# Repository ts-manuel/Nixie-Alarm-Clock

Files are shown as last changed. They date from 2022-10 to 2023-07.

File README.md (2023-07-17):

# Nixie Alarm Clock
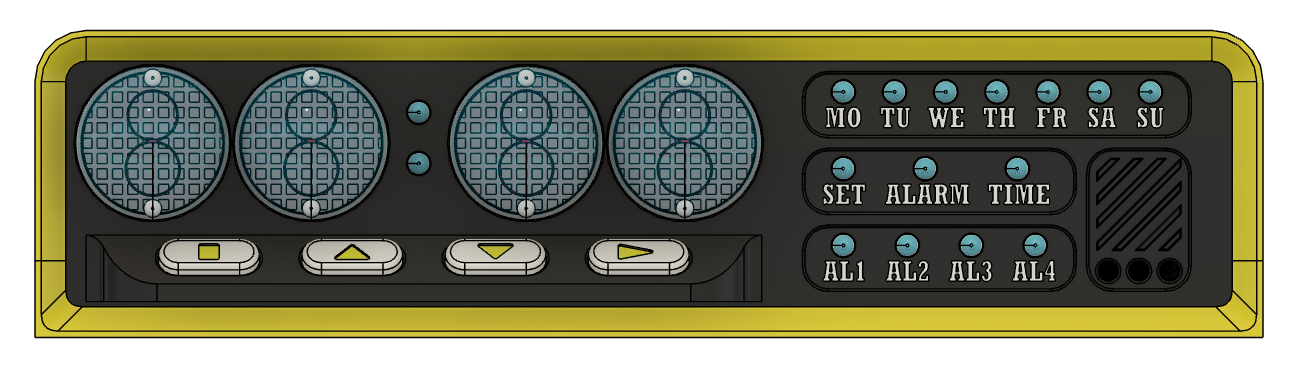
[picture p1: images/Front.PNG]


<!-- TABLE OF CONTENTS -->
<details open="open">
  <summary>Table of Contents</summary>
  <ol>
    <li><a href="#about-the-project">About The Project</a></li>
    <li><a href="#schematics">Schematics</a></li>
    <li><a href="#getting-started">Block Diagram</a></li>
  </ol>
</details>

<!-- ABOUT THE PROJECT -->
## About The Project

<!-- SCHEMATICS -->
## Schematics
[Nixie Alarm Clock - Base.pdf](Nixie%20Alarm%20Clock%20-%20Base.pdf)\
[Nixie Alarm Clock - Display.pdf](Nixie%20Alarm%20Clock%20-%20Display.pdf)

<!-- GETTING STARTED -->
## Getting Started

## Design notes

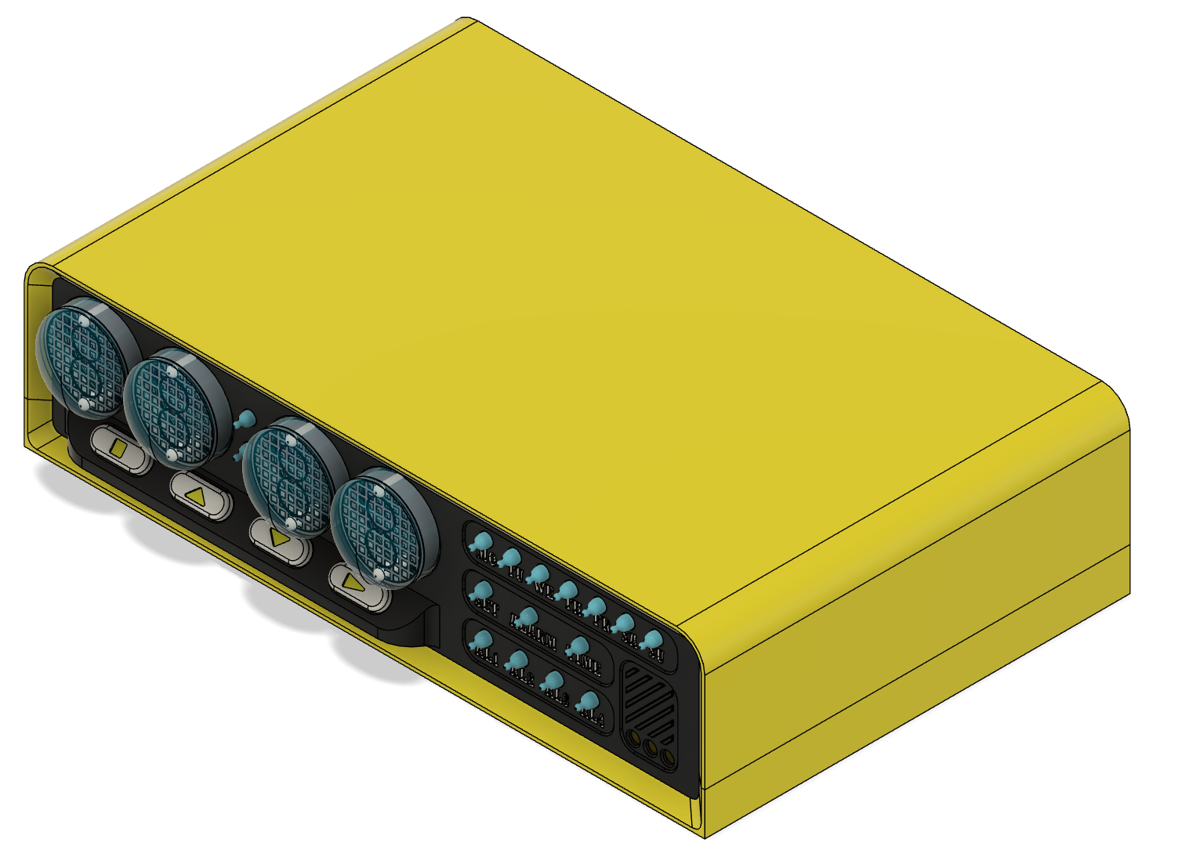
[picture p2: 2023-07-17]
images/home.PNG

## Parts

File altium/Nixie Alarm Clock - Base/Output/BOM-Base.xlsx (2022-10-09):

Mouser Part Number | Description | Designator | Value | Quantity | Footprint
710-150060VS75000 | Standard LEDs - SMD WL-SMCW SMDMono TpVw Waterclr 0603 BrtGrn | D6 | Green | 1 | LED-SMD-0603-1.6X0.8
80-ESK228M025AL4AA | ALU 25V 2200uF RippleCurrent=1.3A 20% | C1, C2 | 2200u | 2 | CAPPRD500W60D1300H2700
603-RC0603FR-07470RL | Thick Film - SMD 75V 1/10W 470 ohm 0603 1% | R9 | 470R | 1 | RES-0603
710-885012007083 | MLCC - SMD 100V 150pF NP0 0805 5% | C35, C36, C37, C38 | 150p | 4 | CAP-0805
603-RC0603FR-07100RL | Thick Film - SMD 75V 1/10W 100 ohm 0603 1% | R14, R15, R16, R23, R24, R25, R26, R29, R30, R31, R32, R34, R36, R37, R38, R39, R40, R41, R42, R43, R44, R45, R46, R47, R48, R52, R53, R55 | 100R | 28 | RES-0603
80-C0603C104M4RAC | MLCC - SMD 16V 100nF X7R 0603 20% | C3, C6, C12, C13, C15, C16, C24, C28, C29, C31, C32, C33, C34 | 100n | 13 | CAP-0603
603-RC0603FR-0754K9L | Thick Film - SMD 75V 1/10W 54.9K ohm 0603 1% | R11 | 54K9 | 1 | RES-0603
603-RC0603FR-0747KL | Thick Film - SMD 75V 1/10W 47K ohm 0603 1% | R17, R18, R19, R20, R21, R22, R27, R28, R33, R50, R54 | 47K | 11 | RES-0603
520-.327-6-34BT | Crystal 32.768kHz 20ppm 6pF -40C +85C | X2 | 32.768 KHz | 1 | XTAL-ECS-3.2 mm x 1.5 mm
80-C0603C270J5G | MLCC - SMD 50V 27pF NP0 0603 5% | C18, C19 | 27p | 2 | CAP-0603
187-CL21A106KAYNNNE | MLCC - SMD 25V 10uF X5R 10% | C4, C5, C7, C8, C9, C10, C11, C14, C17, C22, C23, C26, C27, C39 | 10u | 14 | CAP-0805
603-RC0603FR-0710KL | Thick Film - SMD 75V 1/10W 10K ohm 0603 1% | R13 | 10K | 1 | RES-0603
603-CC603JRNPO9BN8R2 | MLCC - SMD 50V 8.2pF NP0 0603 5% | C20, C21 | 8.2p | 2 | CAP-0603
449-LFXTAL017619BULK | Crystal 7.168MHz 20ppm 30pF -10C +60C | X1 | 7.168 MHz | 1 | XTAL1140X490X430_HC49
603-RC0603FR-074K7L | Thick Film - SMD 75V 1/10W 4.7K ohm 0603 1% | R1, R2, R3, R4, R6, R8, R49, R51 | 4K7 | 8 | RES-0603
963-NRS4018T3R3MDGJ | Fixed Inductor 4018 3.3uH 66mOhms +/-20%Tol 2300mA | L1 | 3u3 | 1 | INDP4040X18M
81-GRM185C1H152JA01J | MLCC - SMD 50V 1.5nF NP0 0603 5% | C25, C30 | 1n5 | 2 | CAP-0603
603-RC0603FR-071K6L | Thick Film - SMD 75V 1/10W 1.6K ohm 0603 1% | R12 | 1K6 | 1 | RES-0603
603-RC0603FR-071KL | Thick Film - SMD 75V 1/10W 1K ohm 0603 1% | R10, R35 | 1K | 2 | RES-0603
603-RC0805FR-071KL | Thick Film - SMD 150V 1/8W 1K ohm 0805 1% | R5, R7 | 1K | 2 | RES-0805
 |  | SW1 |  | 1 | Push Button 6mm TH
 | Header, 3-Pin | P4 |  | 1 | HDR1X3
 | Header, 5-Pin | P3 |  | 1 | HDR1X5
 | Screw Therminal Block 200 mil Pitch 2 Contacts | J3, J4, J5, J6 |  | 4 | SCREW-TH-BLOCK-200-2
 | Screw Therminal Block 200 mil Pitch 4 Contacts | J7 |  | 1 | SCREW-TH-BLOCK-200-4
517-SD-RSMT-2-MQ-WF | Connettori per schede di memoria SD CARD CONNECTOR | J2 |  | 1 | SD 3M SD-RSMT-2-MQ-WF
538-90130-1112 | Terminali e capicorda 2.54MM CGRIDIII HDR 12P V DR SHRD TIN | J1 |  | 1 | SHDR12W65P254_2X6_1758X975X1110P
579-24FJ64GA705IPT | Microcontrollori a 16 bit - MCU 16-bit, 16 MIPS, 64KB Flash, 16KB RAM | U8 |  | 1 | TSQFP50P900X900X120-48N
595-LMV358IDR | Low-Voltage Rail-to-Rail Output FET Input Dual Operational Amplifier | U10 |  | 1 | SOIC127P600X175-8N
595-PCM1754DBQR | Circuiti integrati convertitori D/A audio 24-Bit 192kHz Stereo Audio DAC | U9 |  | 1 | SOP64P600X175-16N
595-TPS561201DDCT | 4.5-V to 17-V Input, 1-A Synchronous Step-Down Voltage Regulator | U4 |  | 1 | SOT95P278X110-6N
621-1N4004 | Silicon Diode - 400V 50uA 1A | D1, D2, D3, D4 |  | 4 | DIODE-DO41
621-AZ1117IH-ADJTRG1 | LDO 15V Max 1.2V Dropout 1.35A Max | U5 |  | 1 | SOT230P700X180-4M
621-PAM8407DR | 2x3W Stereo Differential Input Class D Audio Amplifier with Up/Down Volume Control | U11 |  | 1 | SOIC127P600X175-16N
712-BAT-HLD-001 | Portabatterie a celle a bottone Linx CR2032 Battery Holder | B1 |  | 1 | BATHLD001-CR2032
782-H11A1 | Optocoupler, Phototransistor Output, With Base Connection | U1, U2, U3 |  | 3 | DIP762W51P254L889H508Q6N
863-BAS20LT3G | Silicon Diode - 200V 0.1uA 200mA | D5 |  | 1 | SOT95P240X110-3N
998-MIC2004-0.5YM5TR | Fixed 0.5A Current Limiting Power Distribution Switches | U7 |  | 1 | SOT23-5
998-MIC2548A-2YM | Programmable Current-Limit High-Side Switch | U6 |  | 1 | SOIC127P600X175-8N

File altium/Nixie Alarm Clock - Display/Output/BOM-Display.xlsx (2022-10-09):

Mouser Part Number | Description | Designator | Value | Quantity | Footprint
603-RT1206FRE07680KL | Thin Film Resistors 680K OHM 1% 50PPM 1/4W | R4, R9, R10, R15, R21, R31, R33, R34, R35, R36, R37, R38, R39, R40, R44, R45, R46, R47, R48, R49, R50, R51, R73, R94 | 680K | 24 | RES-1206
77-VJ0805A471JXBCBC | Condensatori in ceramica multistrato MLCC - SMD/SMT 0805 470pF 100volts C0G 5% | C9 | 470p | 1 | CAP-0805
667-ERJ-U6QFR30V | Resistori a pellicola spessa - SMD 0805 0.25W 1% .30ohms AEC-Q200 | R5, R6, R7, R8 | 300m | 4 | RES-0805
710-885342208002 | Condensatori in ceramica multistrato MLCC - SMD/SMT WCAP-CSMH 200V 0.1uF 1206 10% | C1, C2, C3, C4, C5, C8, C10, C11, C12, C13, C14, C15, C16, C17, C18, C19, C20 | 100nF | 17 | CAP-1206
704-DR127-820-R | Induttori fissi 82uH 4.0A 0.143ohms | L1 | 82uH | 1 | IND-DR127
652-TC33X-2-503E | Resistenze trimmer - SMD 3MM 50KOHMS 25% 0.1WATT OPEN FRM | R22, R32, R74 | 50K | 3 | TC33X2503E
603-RT0805FRE0747KL | Thin Film Resistors 1/8W 47K ohm 1% 50ppm | R14, R16, R23, R24, R25, R26, R41, R42, R43, R52, R53, R54, R55, R56, R57, R58, R59, R60, R61, R62, R63, R64, R65, R75, R76, R90, R91, R92, R93 | 47K | 29 | RES-0805
80-A768EB336M1GLAE45 | Condensatori a polimeri organici in alluminio 40V 33uF 20% ESR=45mOhms | C6, C7 | 33uF | 2 | CAPAE7366X60M
652-CR0805JW-150ELF | Resistori a pellicola spessa - SMD 15ohm 5% | R11 | 15R | 1 | RES-0805
603-RT0805FRE134K7L | Thin Film Resistors 4.7K ohm 1% 50 ppm | R1, R2, R3, R12, R13, R17, R18, R19, R20, R27, R28, R29, R30, R66, R67, R68, R69, R70, R71, R72, R77, R78, R79, R80, R81, R82, R83, R84, R85, R86, R87, R88, R89 | 4K7 | 33 | RES-0805
 |  | D5, D6, D7, D8 |  | 4 | IN4 NIXIE
 |  | SW1, SW2, SW3, SW4 |  | 4 | Push Button 6mm TH
78-BZM55C47 | Diodi Zener 47 Volt 0.5W 5% | D3, D4 |  | 2 | DIOMELF1913M
511-MC34063ABD-TR | DC-DC Converter 3.0 to 40V | U1 |  | 1 | SOIC-8_3.9X4.9
512-FDT86244 | MOSFET 150V N-Channel PowerTrench MOSFET | Q1 |  | 1 | SOT230P700X180-4M
538-90130-1112 | Terminali e capicorda 2.54MM CGRIDIII HDR 12P V DR SHRD TIN | J1 |  | 1 | SHDR12W65P254_2X6_1758X975X1110P
595-CD74HC595M96 | 8-Bit Shift Register | U2, U4, U6, U8, U10 |  | 5 | SOIC127P600X175-16N
595-SN75468DR | High Voltage Darlington Transistor Arrays | U3, U5, U7, U9, U11 |  | 5 | SOIC127P600X175-16N
621-MMBTA42-F | 300V NPN SMALL SIGNAL TRANSISTOR IN SOT23 | Q9, Q15, Q24, Q25, Q26, Q27, Q28, Q29, Q30, Q31, Q40 |  | 11 | SOT95P240X110-3N
621-MMBTA92-F | 300V PNP SMALL SIGNAL TRANSISTOR IN SOT23 | Q2, Q3, Q4, Q5, Q6, Q7, Q8, Q10, Q11, Q12, Q13, Q14, Q16, Q17, Q18, Q19, Q20, Q21, Q22, Q23, Q32, Q33, Q34, Q35, Q36, Q37, Q38, Q39, Q41, Q42, Q43, Q44, Q45, Q46, Q47, Q48, Q49 |  | 37 | SOT95P240X110-3N
696-GT-NE4H1125 | Lampade Std. Brightness Neon Lamp Tin Leads | N1, N2, N3, N4, N5, N6, N7, N8, N9, N10, N11, N12, N13, N14, N15, N16 |  | 16 | NE4 NEON LAMP
755-RFN2LAM4STR | Diodi - Uso generico, alimentazione, commutazione 400V 1.5A Io PMDTM | D1, D2 |  | 2 | SODFL472X100-2M

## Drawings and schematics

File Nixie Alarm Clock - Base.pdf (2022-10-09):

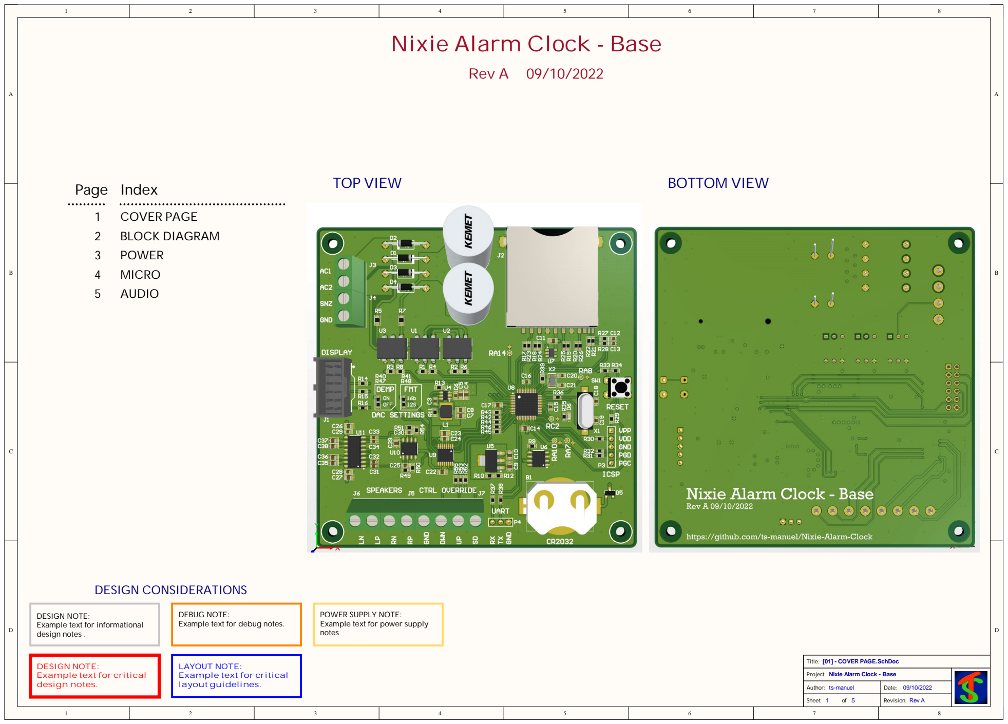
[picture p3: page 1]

DESIGN NOTE:
Example text for informational
design notes .

DEBUG NOTE:
Example text for debug notes.

POWER SUPPLY NOTE:
Example text for power supply
notes

Example text for critical
design notes.

LAYOUT NOTE:
layout guidelines.

Nixie Alarm Clock - Base

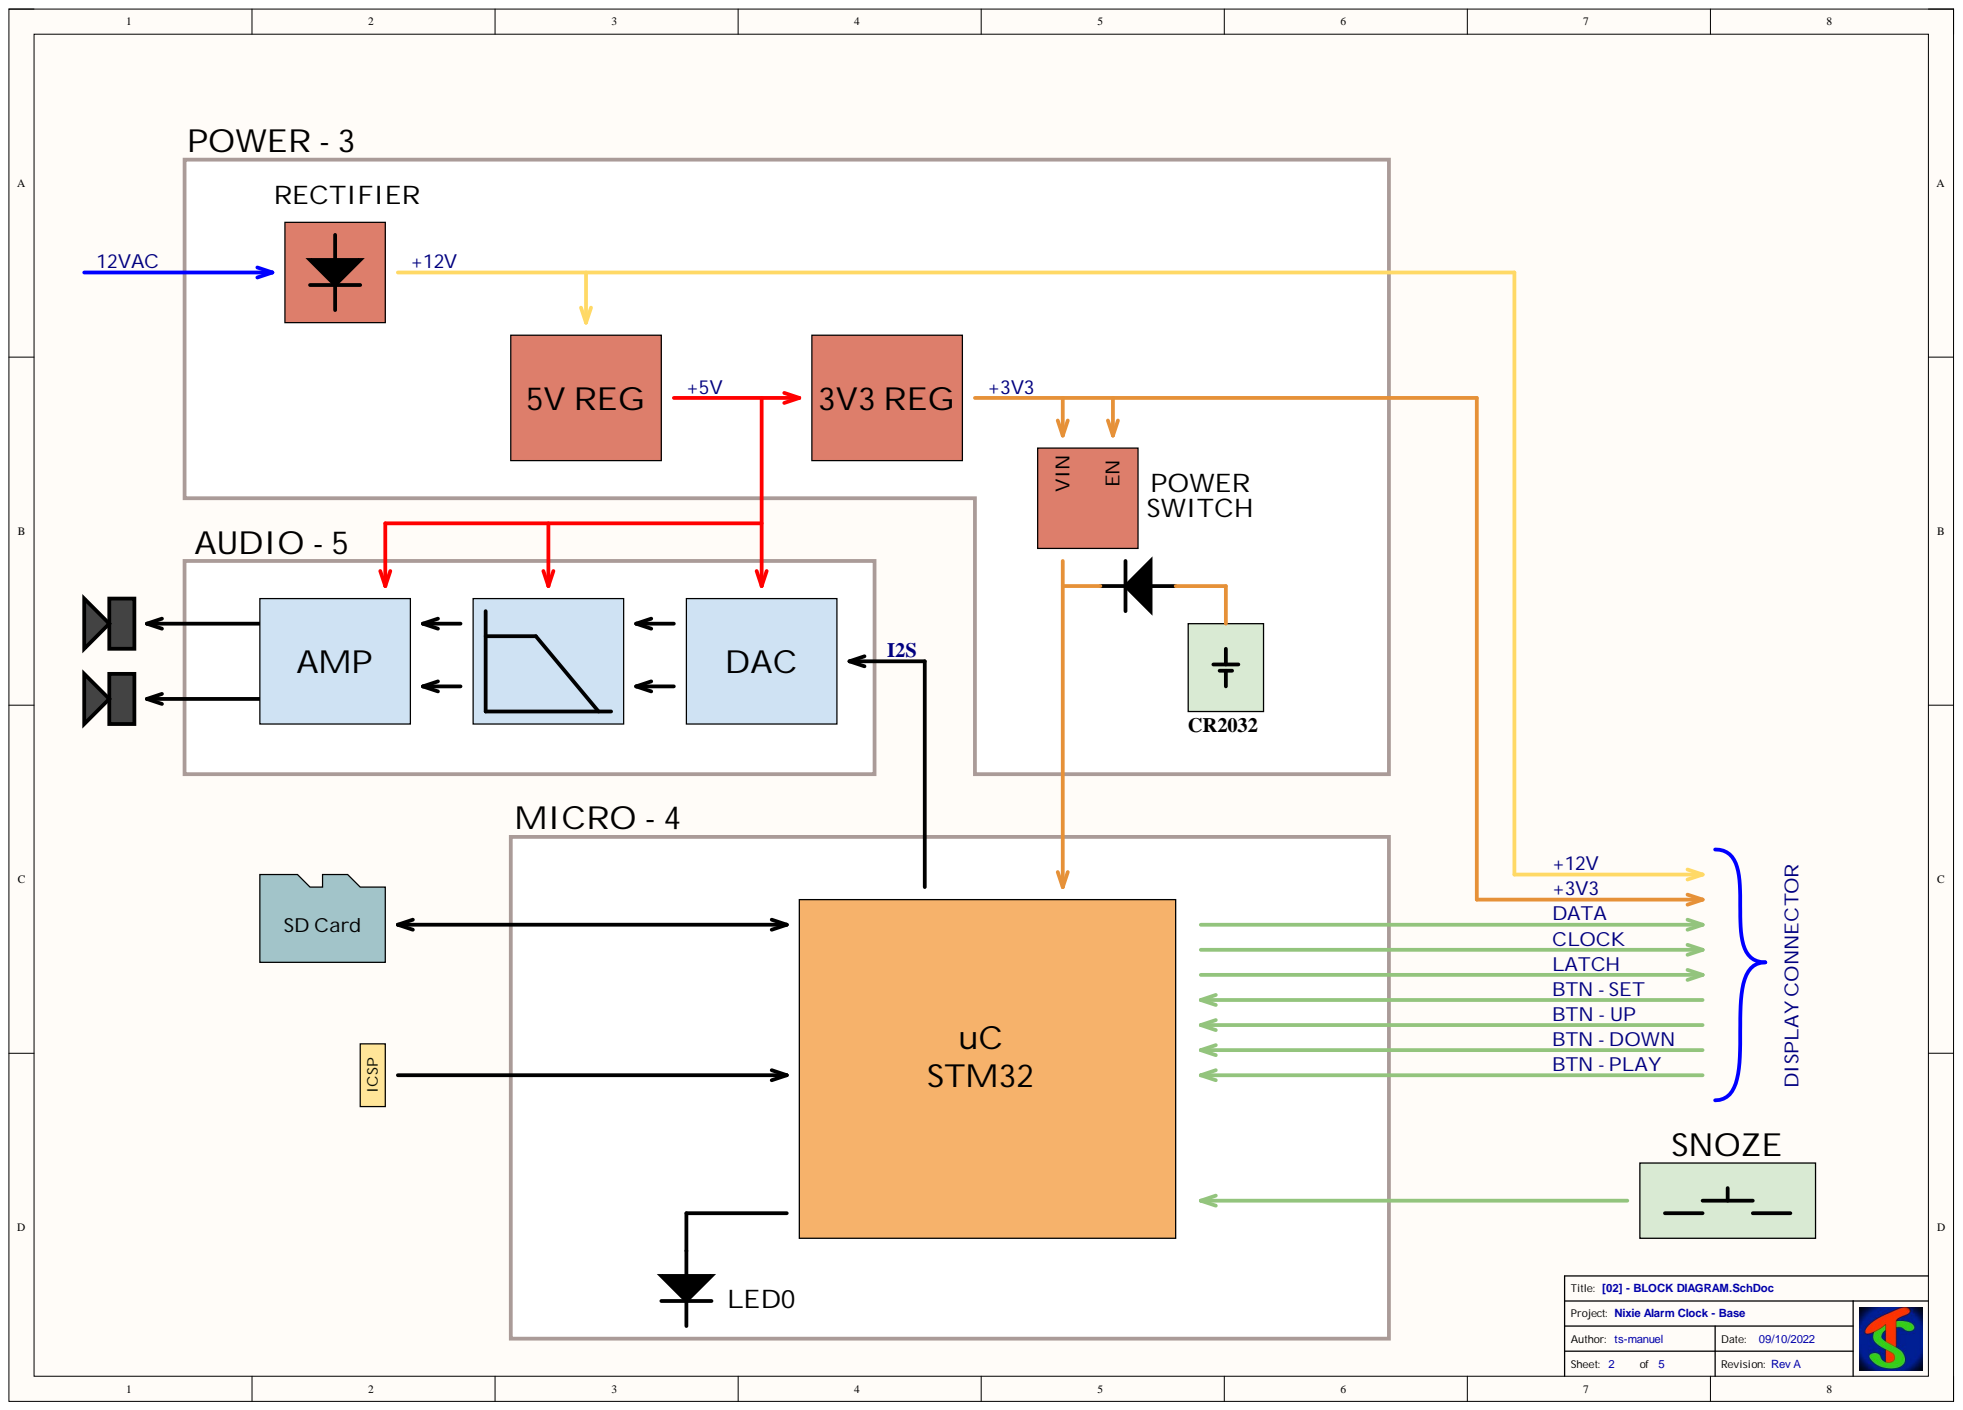
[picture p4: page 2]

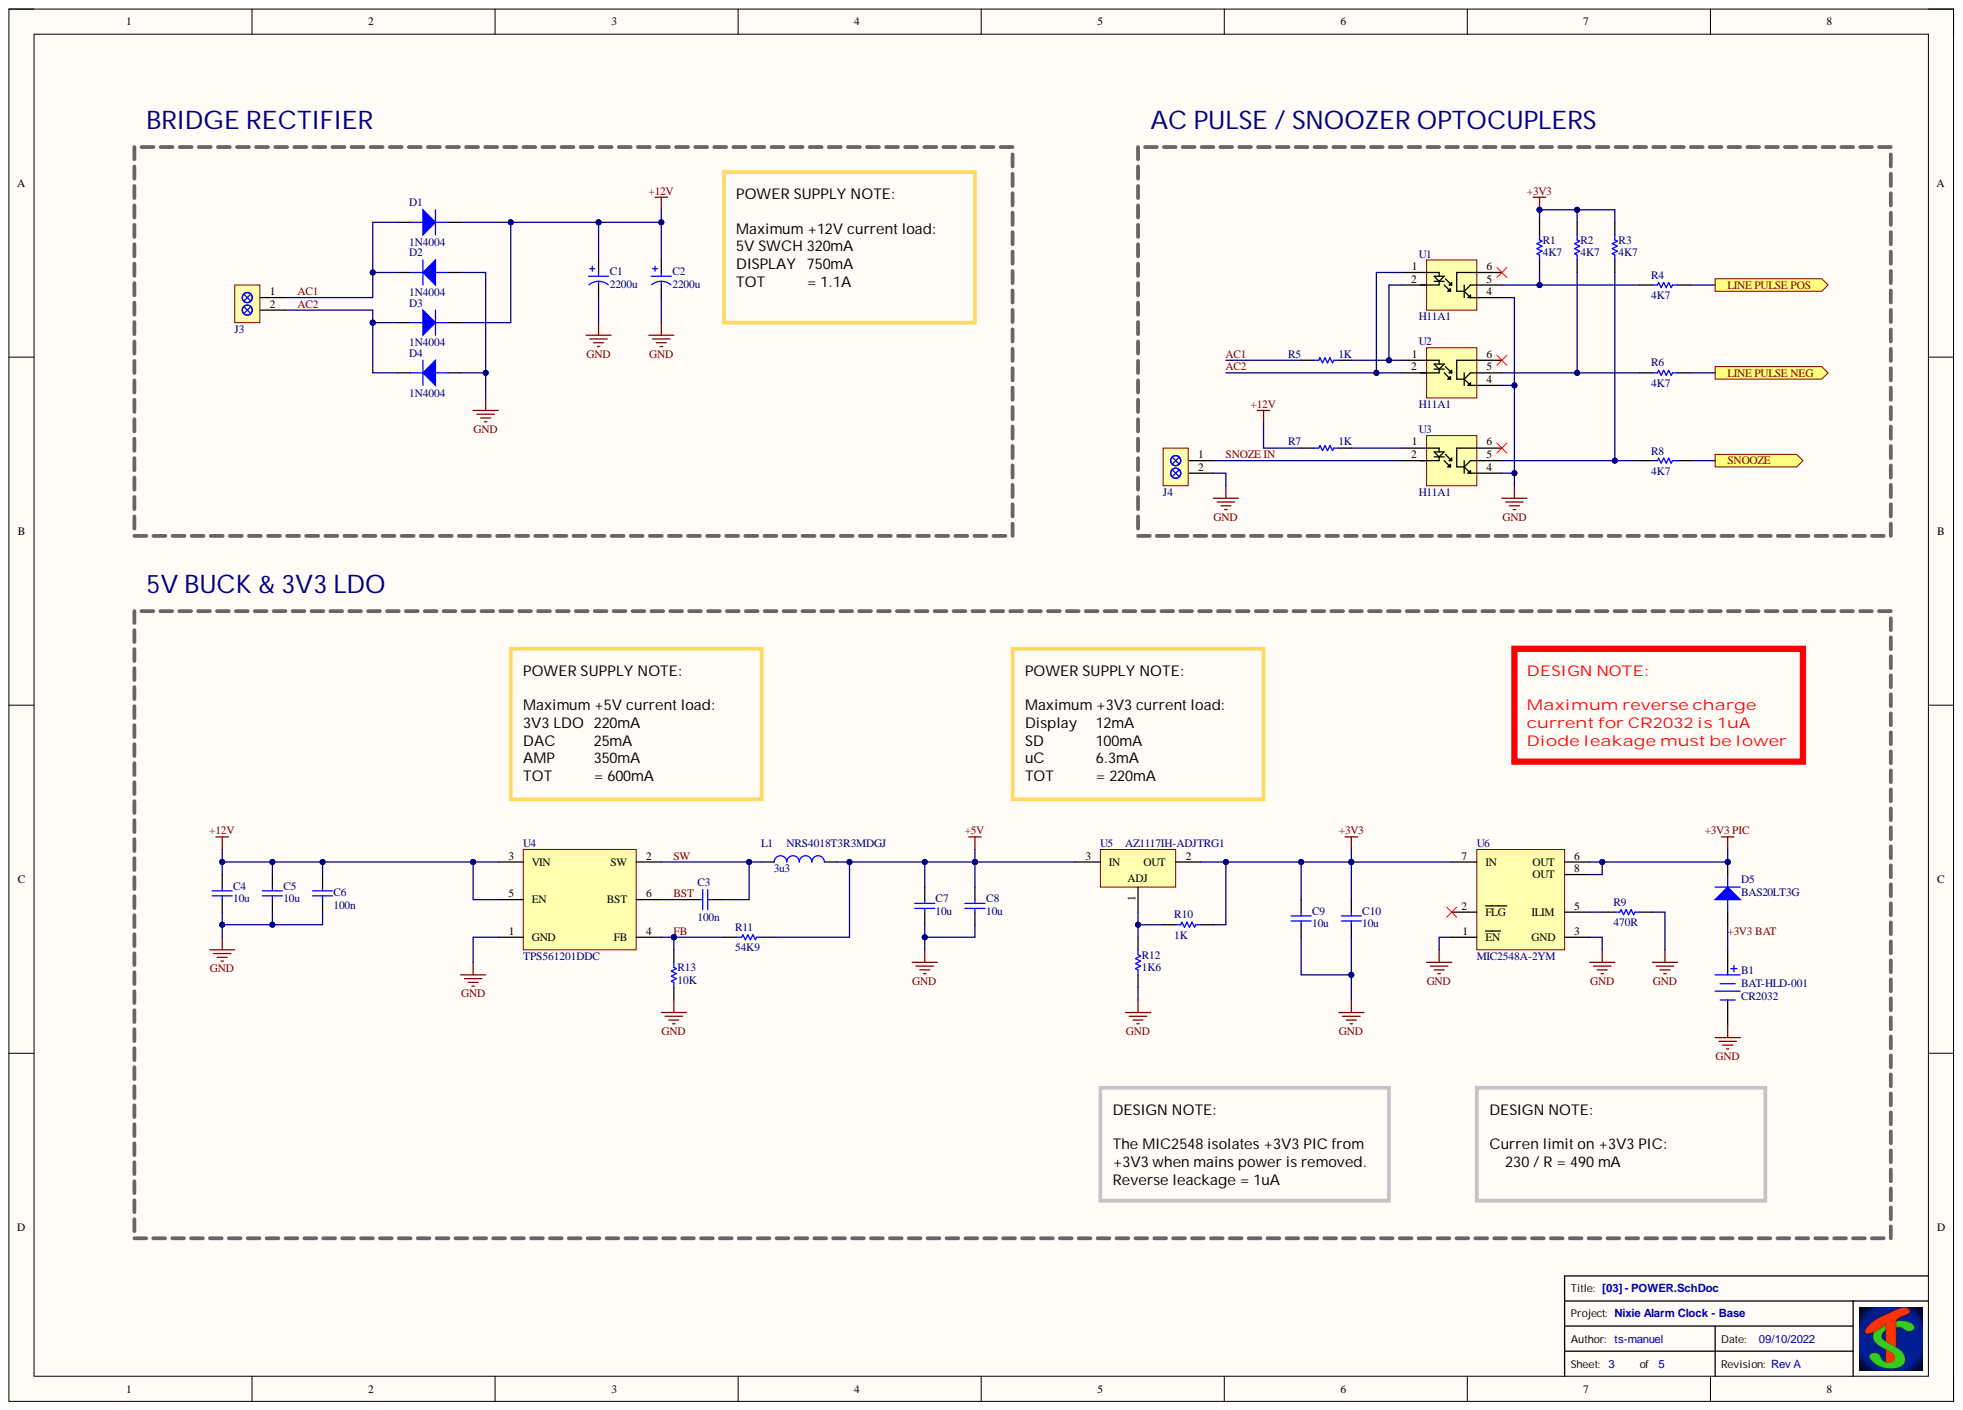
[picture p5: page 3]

Maximum reverse charge
current for CR2032 is 1uA
Diode leakage must be lower

The MIC2548 isolates +3V3 PIC from
+3V3 when mains power is removed.
Reverse leackage = 1uA

Curren limit on +3V3 PIC:

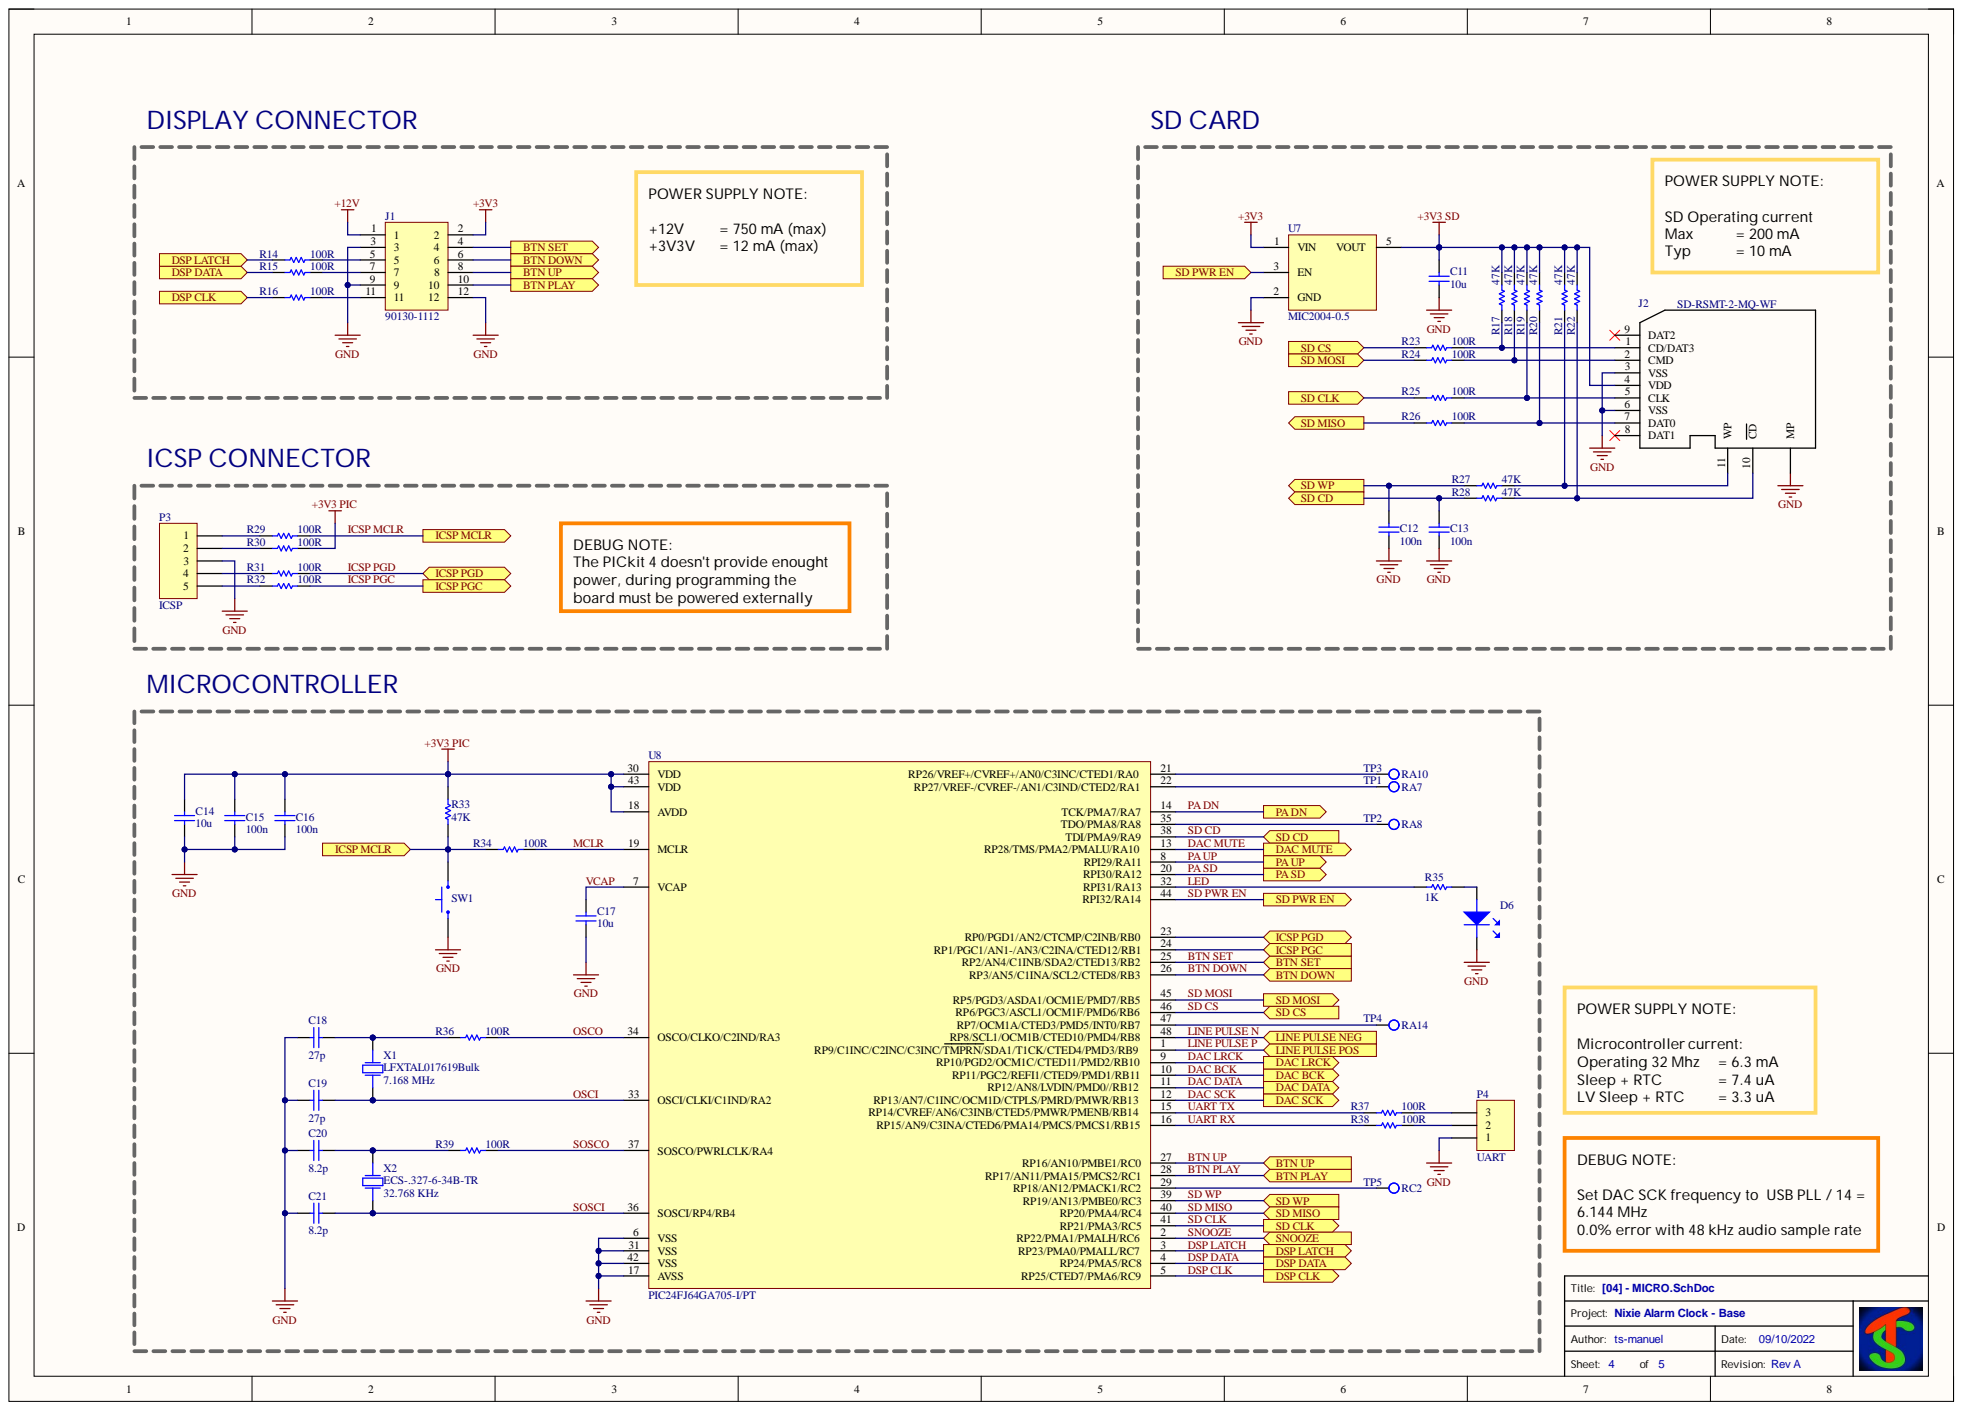
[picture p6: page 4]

CMD 2
VSS 3
VDD 4
CLK 5

DAT0 7

The PICkit 4 doesn't provide enought
power, during programming the
board must be powered externally

DAC MUTE
R35 LED
SD PWR EN

BTN SET
BTN DOWN

SD MOSI

LINE PULSE POS LINE PULSE P

DAC DATA
DAC SCK
UART TX
UART RX

BTN UP
BTN PLAY

SD MISO
SD CLK
SNOOZE
DSP LATCH
DSP DATA
DSP CLK

Set DAC SCK frequency to USB PLL / 14 =
6.144 MHz
0.0% error with 48 kHz audio sample rate

VSS 31

AVSS 17

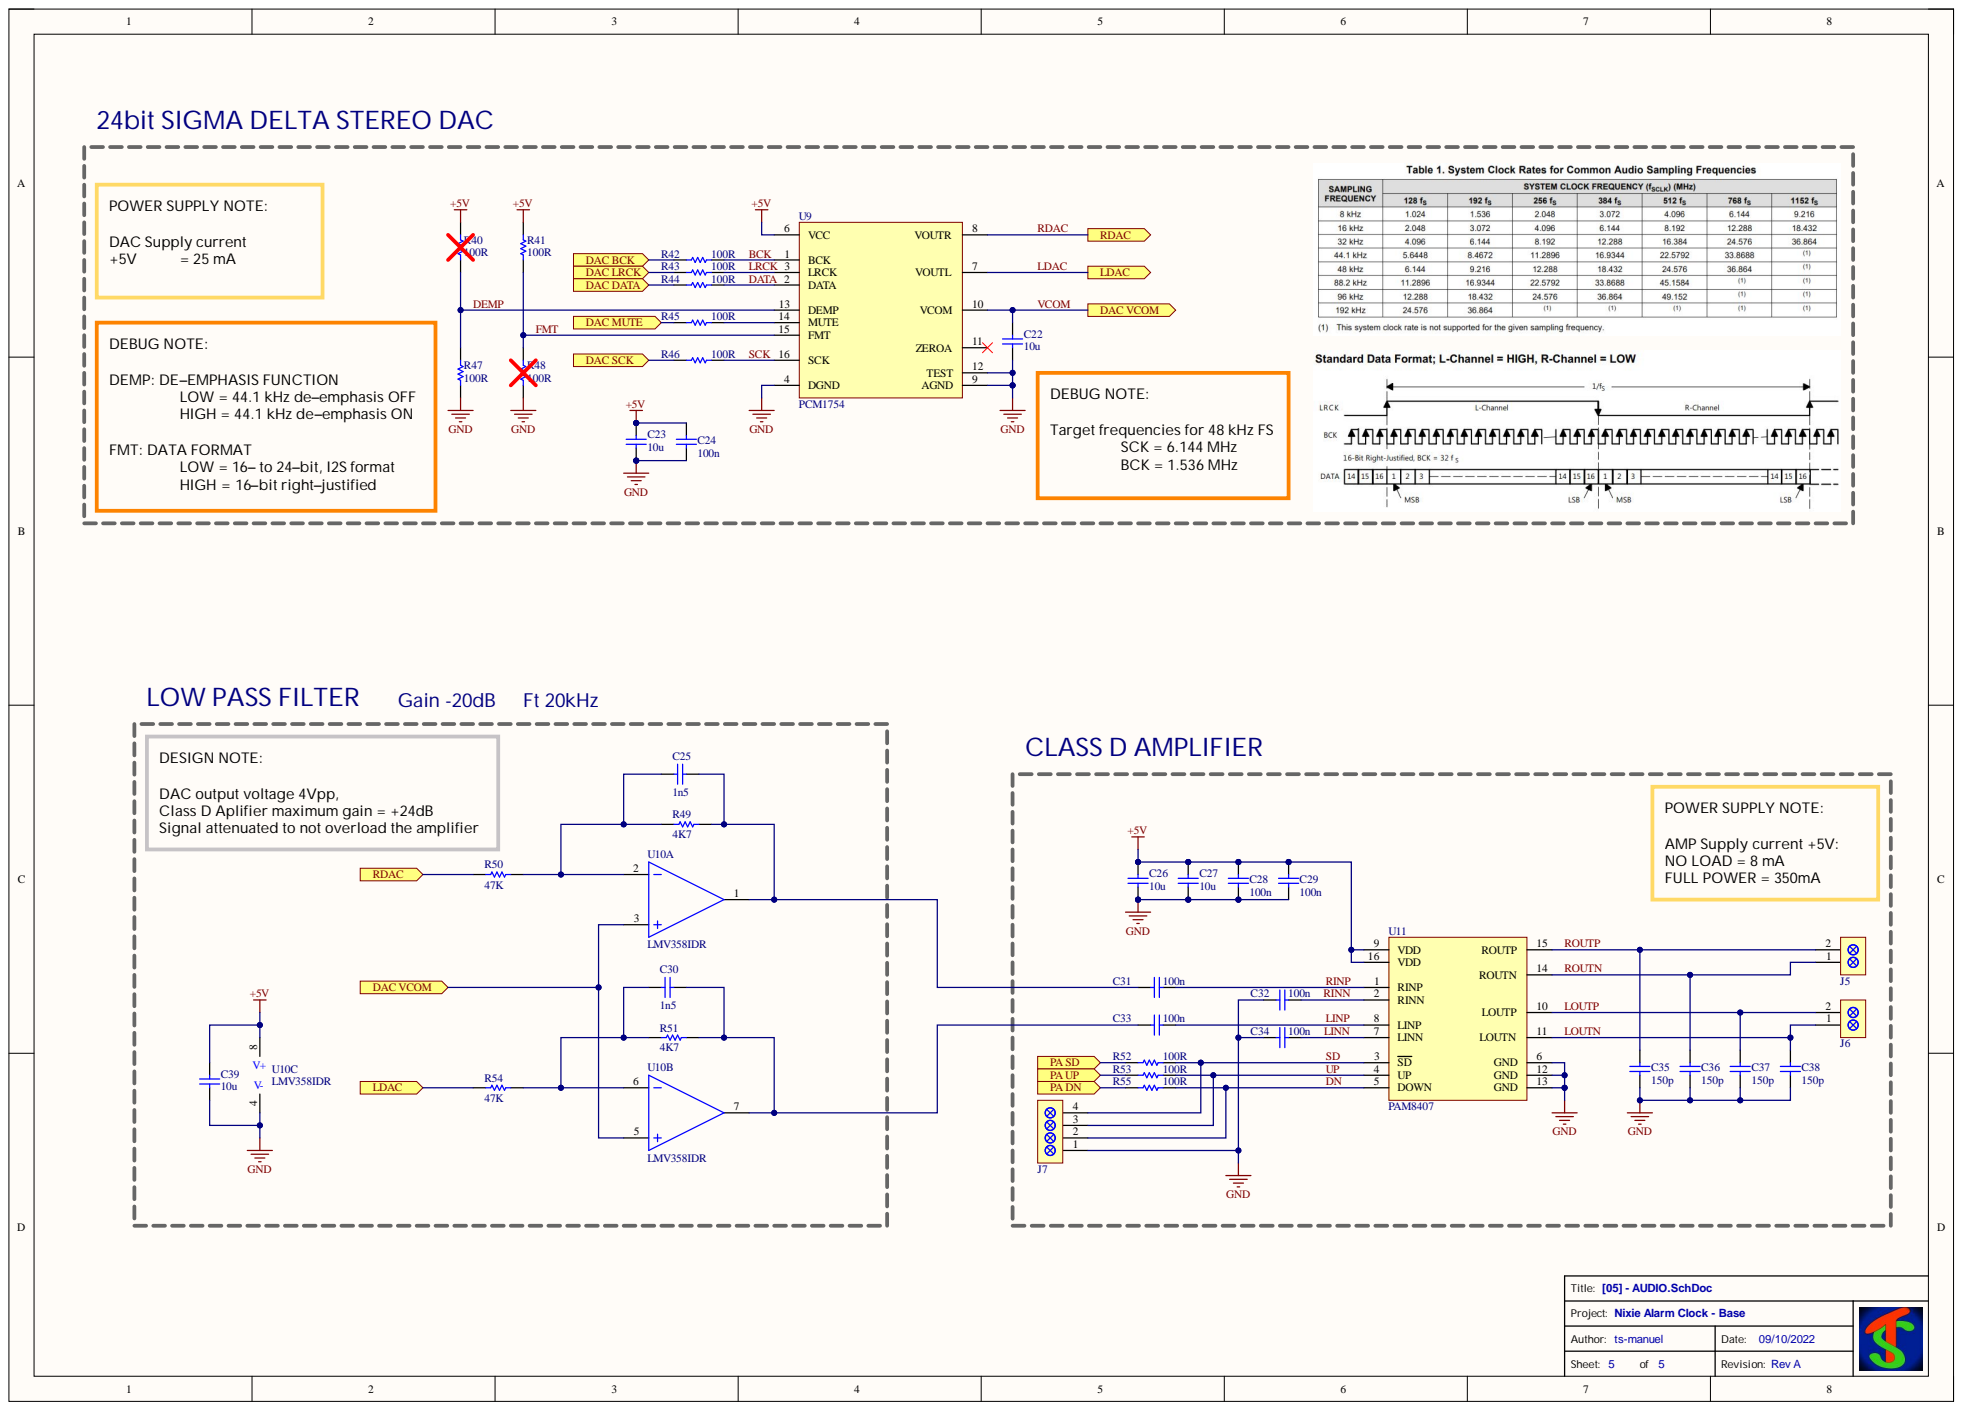
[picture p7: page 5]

24bit SIGMA DELTA STEREO DAC

DEMP: DE–EMPHASIS FUNCTION

LOW = 44.1 kHz de–emphasis OFF
HIGH = 44.1 kHz de–emphasis ON

Target frequencies for 48 kHz FS

LOW = 16– to 24–bit, I2S format
HIGH = 16–bit right–justified

DAC output voltage 4Vpp,
Class D Aplifier maximum gain = +24dB
Signal attenuated to not overload the amplifier

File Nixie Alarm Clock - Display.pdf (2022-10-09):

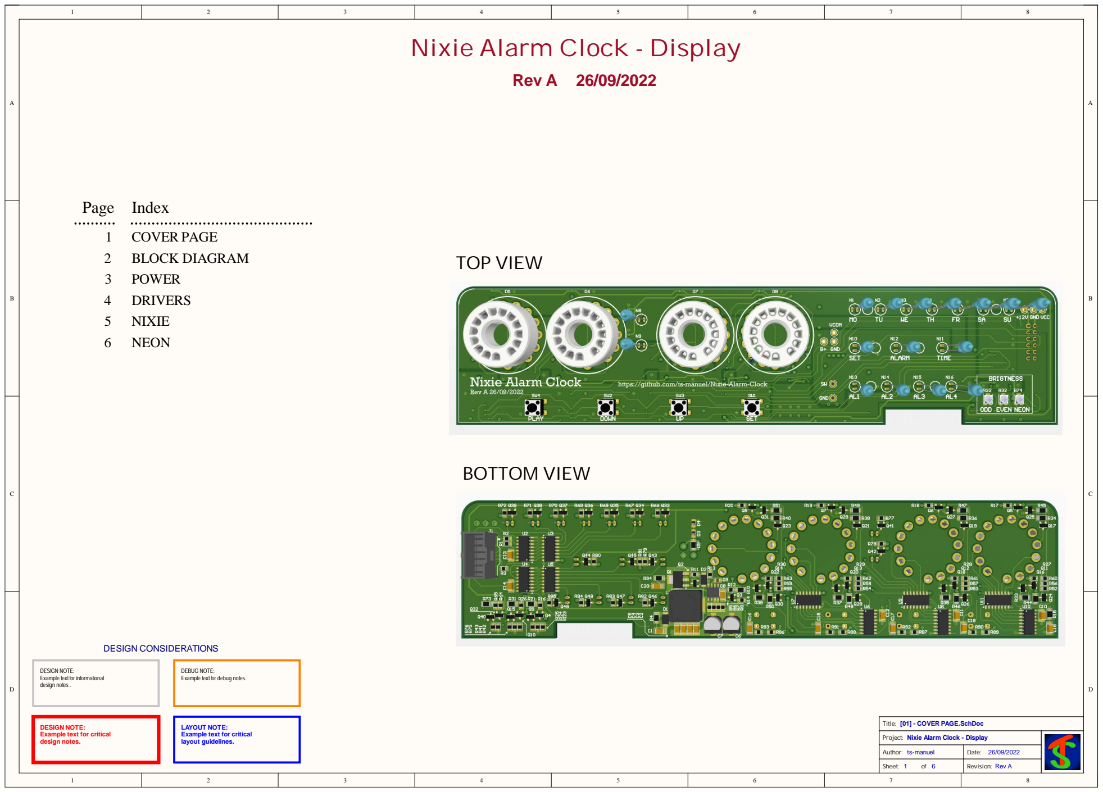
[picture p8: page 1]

DESIGN NOTE:
Example text for informational
design notes .

DEBUG NOTE:
Example text for debug notes.

Example text for critical
design notes.

LAYOUT NOTE:
layout guidelines.

Nixie Alarm Clock - Display

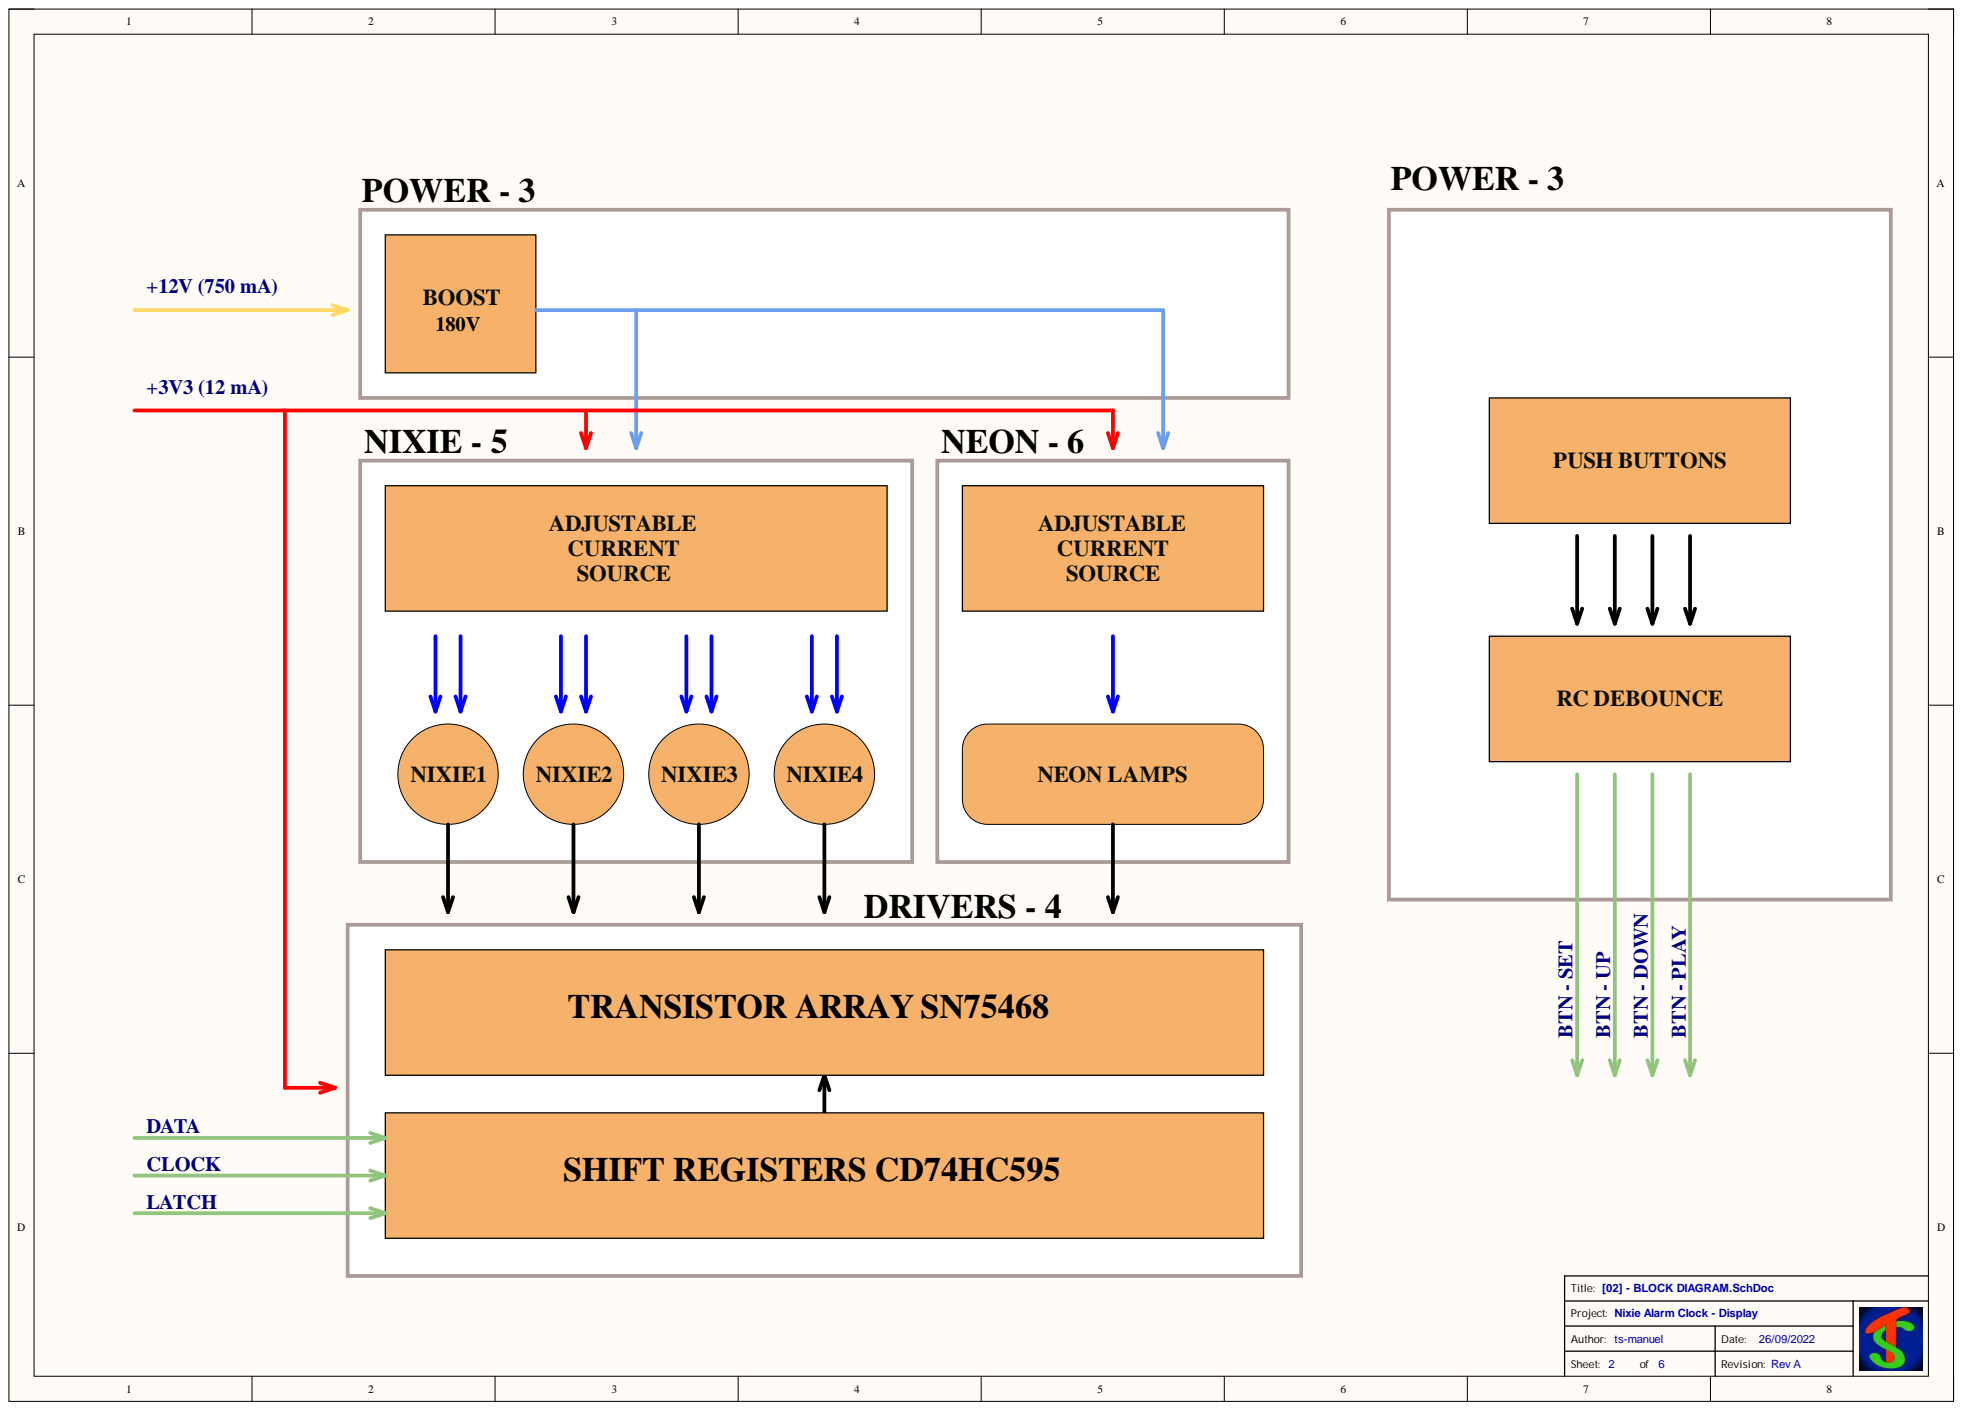
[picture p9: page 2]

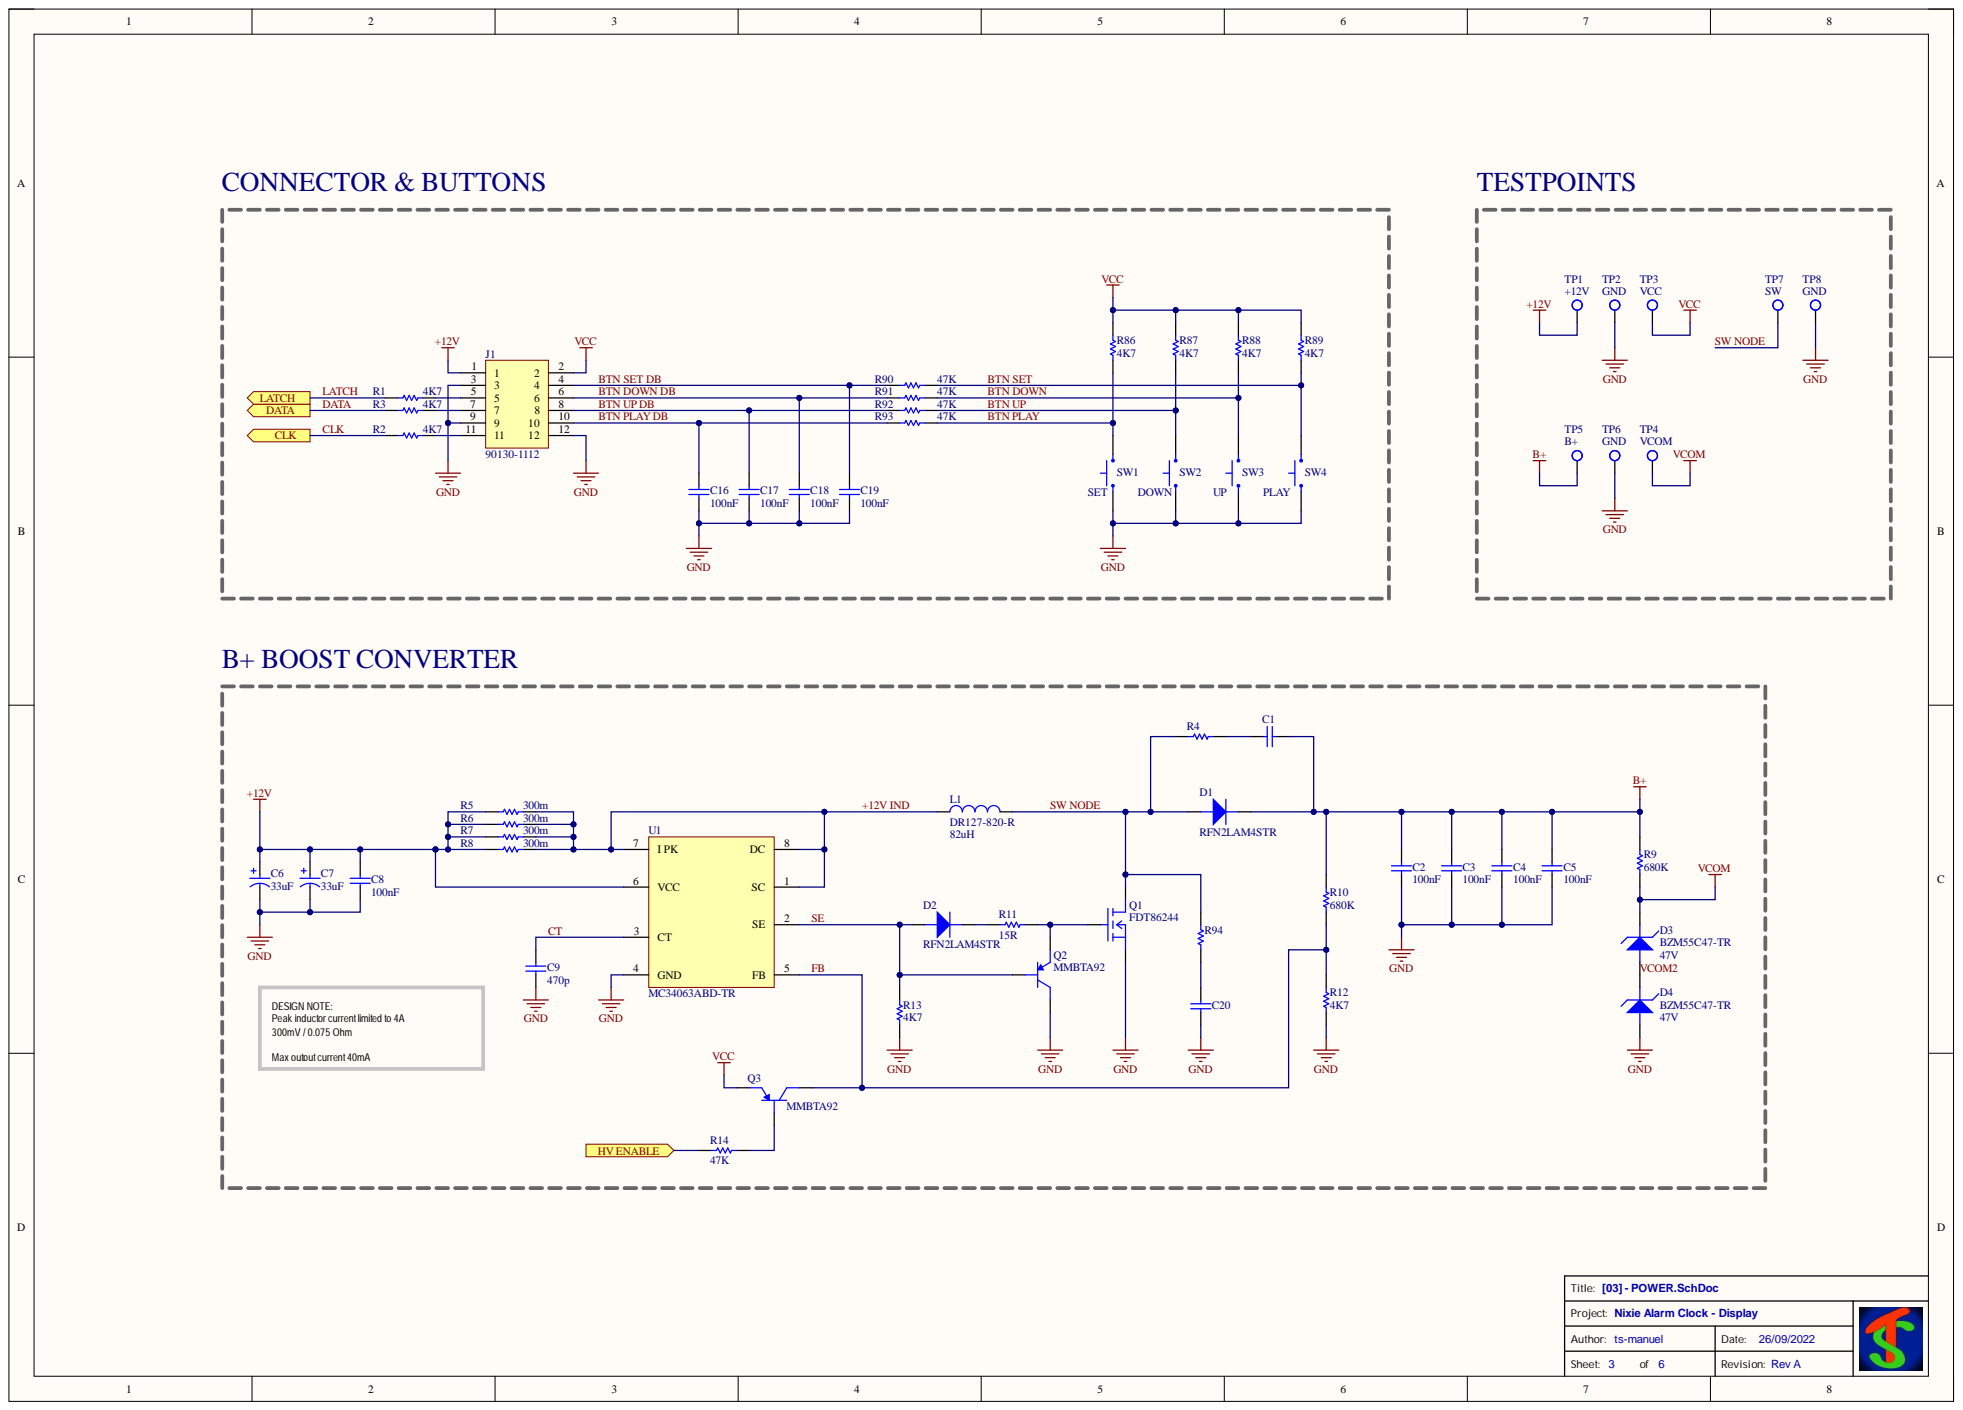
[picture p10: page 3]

5 5 7 7 9 9 | BTN DOWN DB

BTN UP DB
BTN PLAY DB

DESIGN NOTE:
Peak inductor current limited to 4A
300mV / 0.075 Ohm

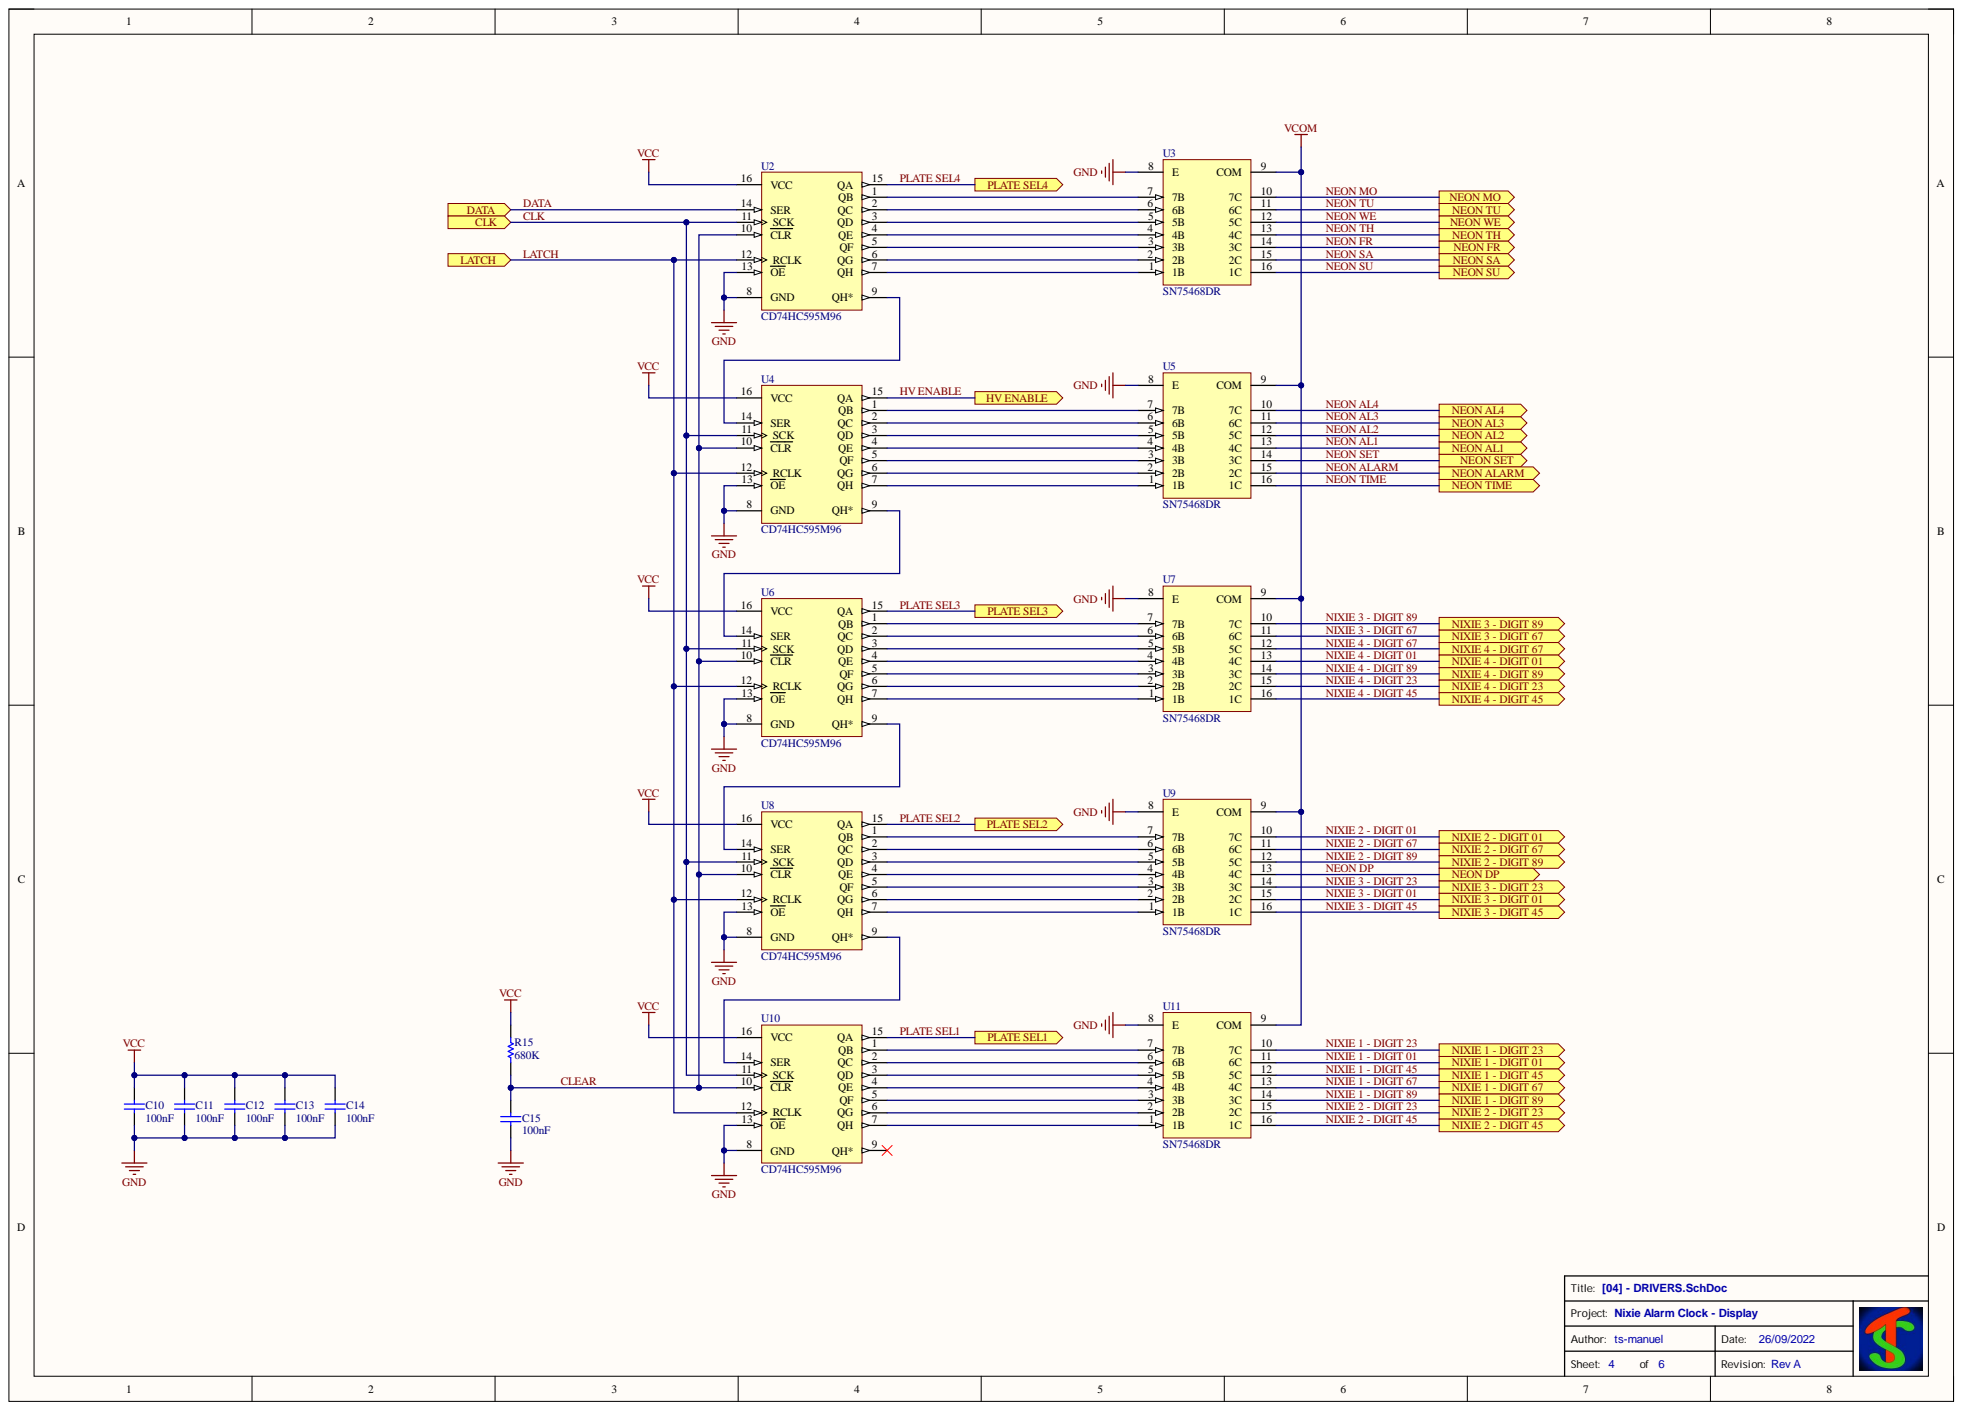
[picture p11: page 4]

GND 8

HV ENABLE

NEON AL4
NEON AL3
NEON AL2
NEON AL1
NEON SET
NEON ALARM
NEON TIME

NIXIE 4 - DIGIT 67

NIXIE 4 - DIGIT 23
NIXIE 4 - DIGIT 45

NIXIE 1 - DIGIT 23
NIXIE 1 - DIGIT 01
NIXIE 1 - DIGIT 45
NIXIE 1 - DIGIT 67
NIXIE 1 - DIGIT 89
NIXIE 2 - DIGIT 23
NIXIE 2 - DIGIT 45

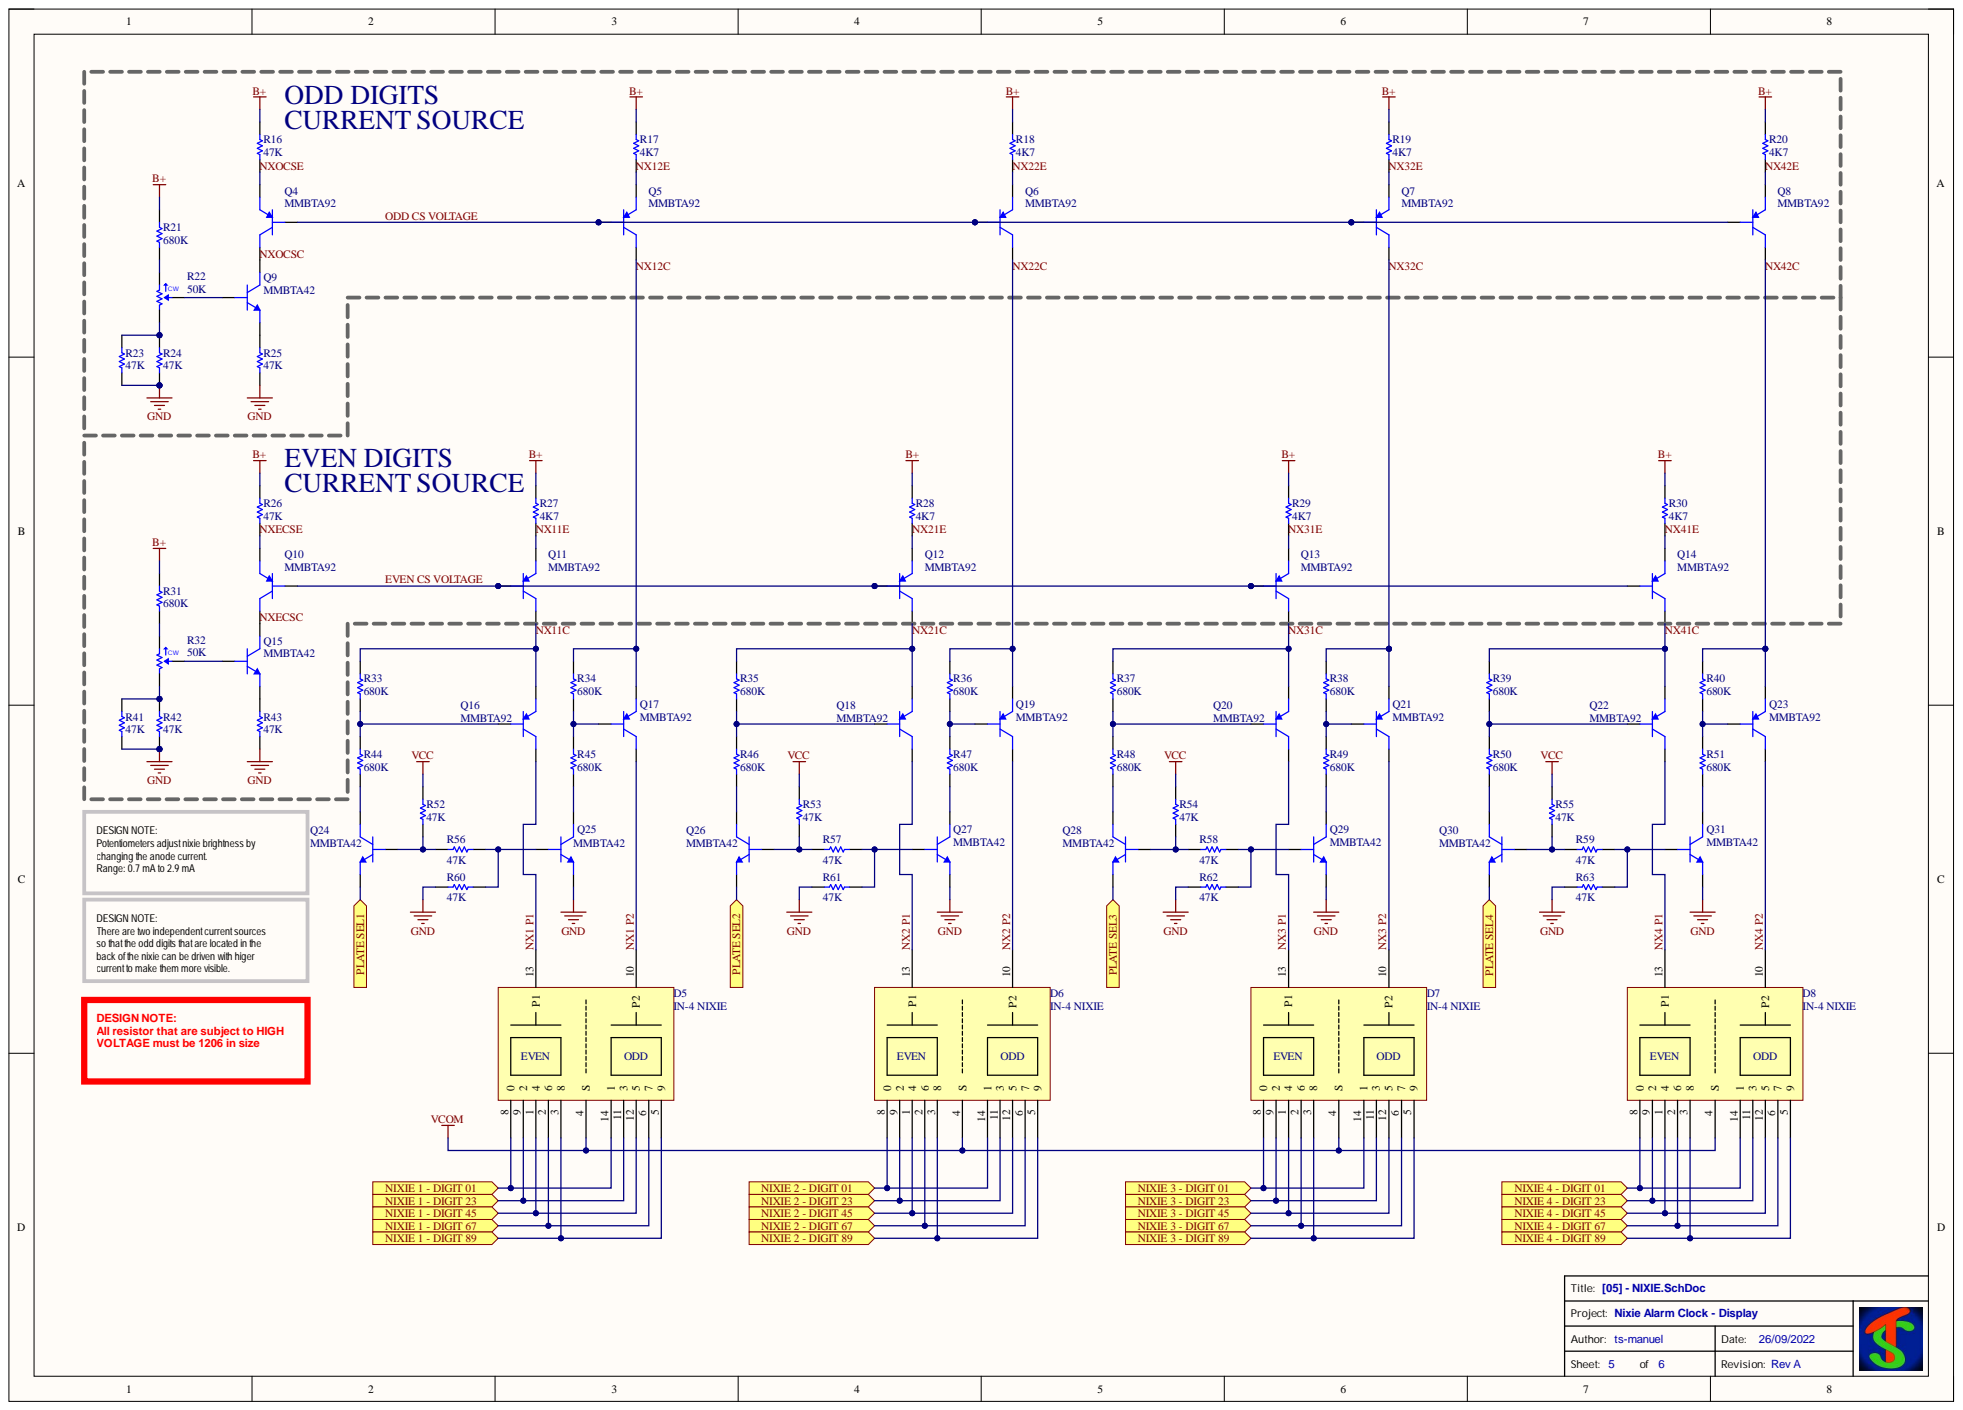
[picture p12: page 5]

DESIGN NOTE:
Potentiometers adjust nixie brightness by
changing the anode current.
Range: 0.7 mA to 2.9 mA

There are two independent current sources
so that the odd digits that are located in the
back of the nixie can be driven with higer
current to make them more visible.

All resistor that are subject to HIGH
VOLTAGE must be 1206 in size

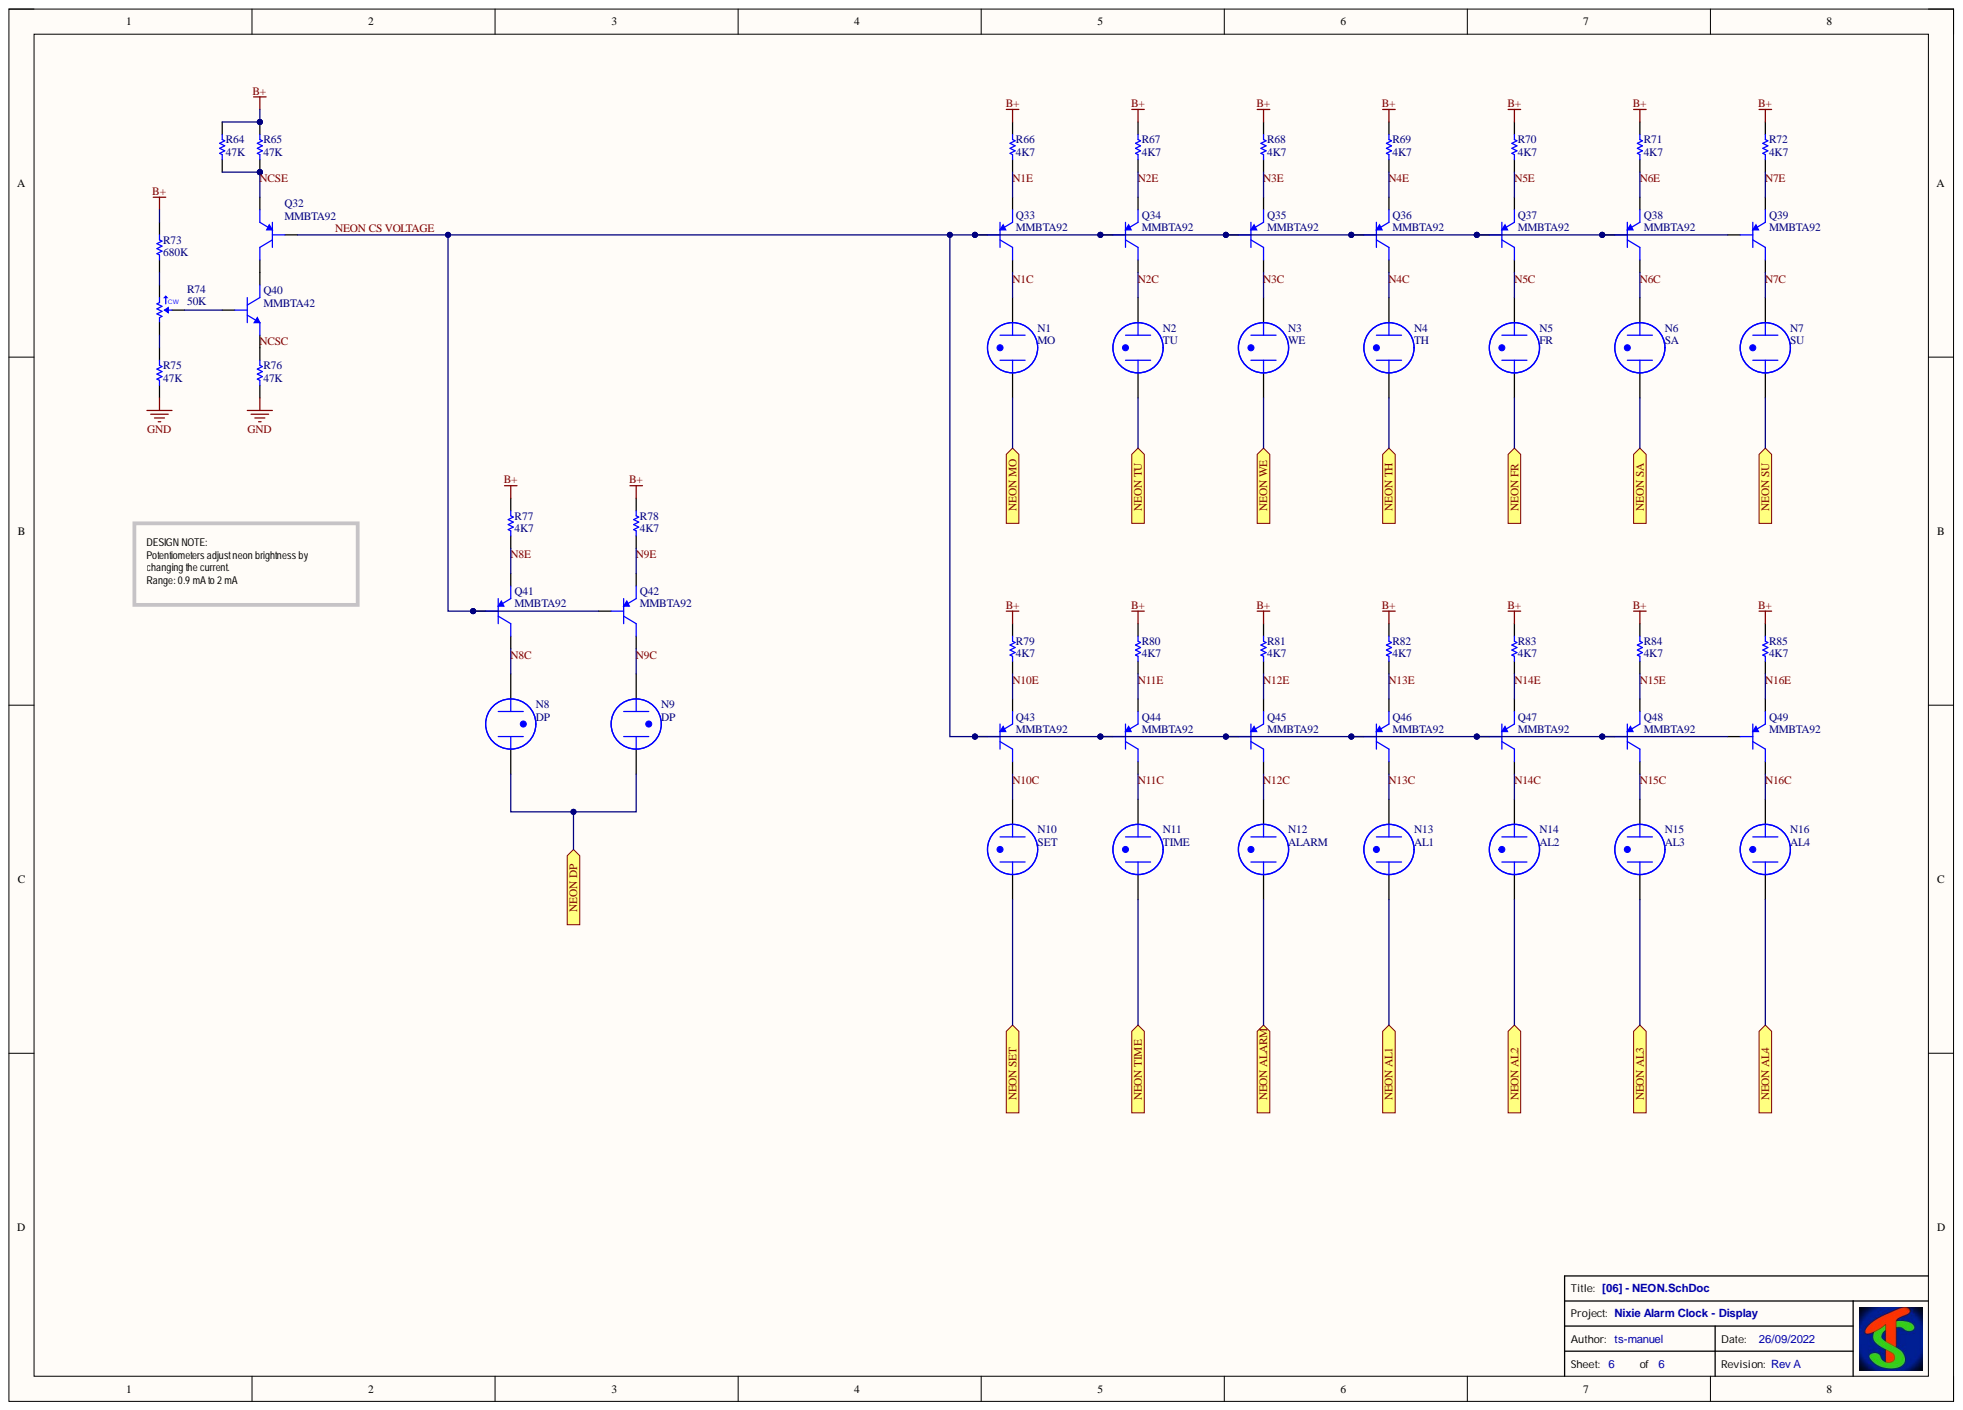
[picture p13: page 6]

DESIGN NOTE:
Potentiometers adjust neon brightness by
changing the current.
Range: 0.9 mA to 2 mA

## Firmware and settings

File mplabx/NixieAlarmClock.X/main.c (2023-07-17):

/**
  Generated main.c file from MPLAB Code Configurator

  @Company
    Microchip Technology Inc.

  @File Name
    main.c

  @Summary
    This is the generated main.c using PIC24 / dsPIC33 / PIC32MM MCUs.

  @Description
    This source file provides main entry point for system initialization and application code development.
    Generation Information :
        Product Revision  :  PIC24 / dsPIC33 / PIC32MM MCUs - 1.171.1
        Device            :  PIC24FJ64GA705
    The generated drivers are tested against the following:
        Compiler          :  XC16 v1.70
        MPLAB 	          :  MPLAB X v5.50
*/

/*
    (c) 2020 Microchip Technology Inc. and its subsidiaries. You may use this
    software and any derivatives exclusively with Microchip products.

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
    IN NO EVENT WILL MICROCHIP BE LIABLE FOR ANY INDIRECT, SPECIAL, PUNITIVE,
    INCIDENTAL OR CONSEQUENTIAL LOSS, DAMAGE, COST OR EXPENSE OF ANY KIND
    WHATSOEVER RELATED TO THE SOFTWARE, HOWEVER CAUSED, EVEN IF MICROCHIP HAS
    BEEN ADVISED OF THE POSSIBILITY OR THE DAMAGES ARE FORESEEABLE. TO THE
    FULLEST EXTENT ALLOWED BY LAW, MICROCHIP'S TOTAL LIABILITY ON ALL CLAIMS IN
    ANY WAY RELATED TO THIS SOFTWARE WILL NOT EXCEED THE AMOUNT OF FEES, IF ANY,
    THAT YOU HAVE PAID DIRECTLY TO MICROCHIP FOR THIS SOFTWARE.

    MICROCHIP PROVIDES THIS SOFTWARE CONDITIONALLY UPON YOUR ACCEPTANCE OF THESE
    TERMS.
*/

/**
  Section: Included Files
*/
#include <stdio.h>
#include <stdint.h>
#include <stdbool.h>
#include "system.h"
#include "rtcc.h"
#include "tmr1.h"
#include "pin_manager.h"
#include "utils/millis.h"
#include "utils/delay.h"
#include "utils/logging.h"
#include "tasks/display.h"
#include "tasks/buttons.h"
#include "tasks/alarm.h"
#include "tasks/time.h"
#include "tasks/player.h"
#include "tasks/settings.h"
#include "views/views.h"
#include "hardware/PAM8407.h"


#define _FW_VER_MAJ 0
#define _FW_VER_MIN 2


/*
                         Main application
 */
int main(void)
{
    // initialize the device
    SYSTEM_Initialize();
    
    // Set UART1 baud rate, code-configurator doesn't support 7.168 MHz as clock frequency
    //U1BRG = 0x174; // 9600
    U1BRG = 186;    // 19200
    TIME_delay_ms(1);
    printf("\n\n");
    
    SETTINGS_Initialize();
    BTN_Initialize();
    VIEWS_Initialize();
    DISPLAY_Initialize();
    DISPLAY_SetPower(true);
    PLAYER_Initialize();
    
    // Read RTC time
    TIME_Update();

    
    LOG_INFO("\n\n");
    LOG_INFO("--------------------------------------\n");
    LOG_INFO("COLD START FW Ver. %d.%d\n", _FW_VER_MAJ, _FW_VER_MIN);
    LOG_INFO("Time: %d%d:%d%d Day: %d\n", rtcTime.tm_hour >> 4, rtcTime.tm_hour & 0x0f,
            rtcTime.tm_min >> 4, rtcTime.tm_min & 0x0f, rtcTime.tm_wday);
    LOG_INFO("\n");
    LOG_INFO("Settings:\n");
    LOG_INFO("  Volume: %d\n", playerVolume);
    AlarmSlot_t* al;
    for (uint8_t i = 0; i < _ALARM_SLOT_COUNT; i++)
    {
        al = &alarmSlots[i];
        LOG_INFO("  Alarm slot [%d] Time: %d%d:%d%d Day: %02X\n", i, al->hour >> 4, al->hour & 0x0f, al->min >> 4, al->min & 0x0f, al->day);
    }
    LOG_INFO("--------------------------------------\n");
    
    
    while (1)
    {
        static uint32_t lastMillis = 0;
        uint32_t millis = TIME_Millis();
        
        // Heartbeat LED
        if (millis - lastMillis > 500)
        {
            lastMillis = millis;
            O_LED_Toggle();
        }
        
        // Update tasks
        ALARM_Update();
        BTN_Update();
        DISPLAY_Update();
        TIME_Update();
        PLAYER_Update();
        SETTINGS_Update();
        
        // Update views
        VIEWS_Update();
    }

    return 1;
}






/**
 End of File
*/

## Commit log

2022-10-09 Added Display PCB
    [BOM-Display.xlsx, Nixie Alarm Clock - Display.PrjPcb, [01] - COVER PAGE.SchDoc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]
2022-10-09 Added Base PCB
    [BOM-Base.xlsx, Base.PcbDoc, Nixie Alarm Clock - Base.PrjPcb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]
2022-12-11 Added PDF schematics
2023-07-15 Improved millis implementation
    Interrupt from timer1 every millisecond
2023-07-15 improved buttons state machine interface
    Removed the global array of buttons, added getter functions to retrieve the state
2023-07-16 added button configuration in config file
    Added button configuration for long and short presses in the config file.
2023-07-16 moved application state machine inside views
    Application implemented with two nested state machines. The other one switches between views,
    the inner one handles button presses and updates the display for that view.
2023-07-16 created alarm task
    Moved alarm trigger logic in its own task.
    The alarms slots are stored in the global variables file.
    When an alarm triggers a flag is set that needs to be cleared by the task that uses it.
2023-07-16 added time task
    Added time task to read from the THC timer and update a global variable.
2023-07-16 volume instead of attenuation in dac driver
    Setting volume in DAC driver now accepts a value from 0 to 31 where 0 is minimum, 3 is maximum.
2023-07-16 week function override for timer1 ISR
    Override timer1 week ISR instead of using function pointers.
